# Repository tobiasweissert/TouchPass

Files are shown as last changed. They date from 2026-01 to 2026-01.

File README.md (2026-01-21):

# TouchPass



A hardware password manager that types your passwords when you touch it with an enrolled finger.

TouchPass Demo

## Features

- **6-capture enrollment** - Touch ID style enrollment for better accuracy
- **Dual Keyboard Support** - USB HID or BLE Keyboard (switchable via web UI)
- **WiFi AP Configuration** - Configure via web interface at 192.168.4.1
- **USB Serial Configuration** - Alternative USB-based config (no WiFi interference)
- **10 finger support** - Map passwords to specific fingers on left/right hands
- **Re-enrollment protection** - Re-enrolling a finger overwrites the previous entry
- **ESP32-S3 & ESP32-C6 support** - Works with both chips

## Hardware

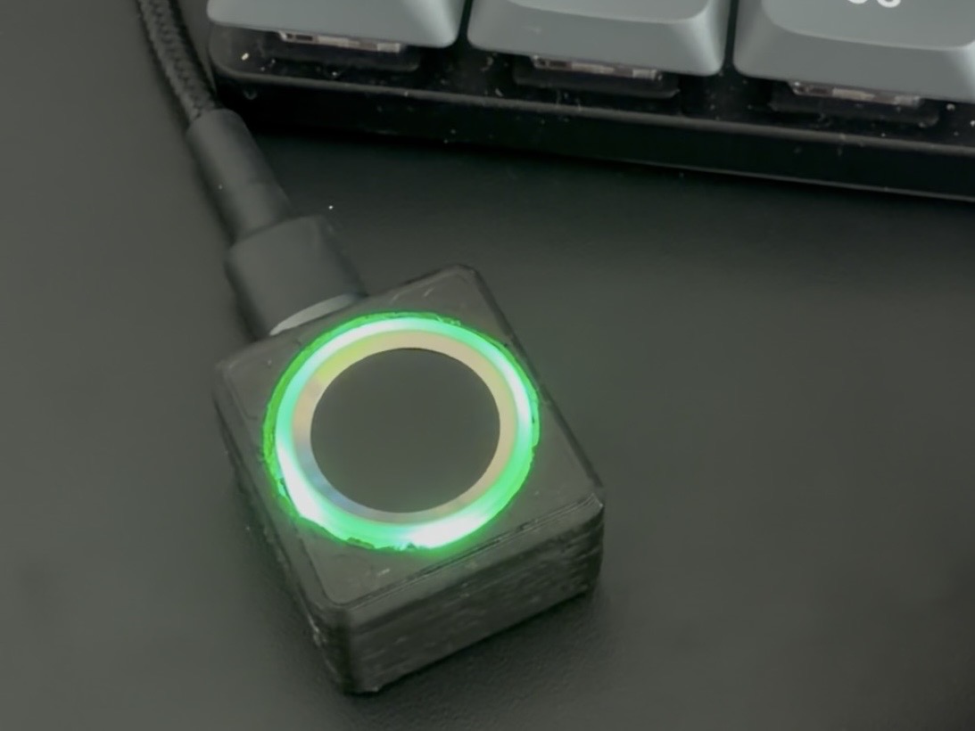
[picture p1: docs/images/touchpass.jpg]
TouchPass Device


| Component | Description |
|---|---|
| Seeed XIAO ESP32-S3 | Recommended - USB HID + WiFi + BLE |
| Seeed XIAO ESP32-C6 | Alternative - BLE only, WiFi 6 |
| R502-A | Capacitive fingerprint sensor with RGB LED |

See [hardware/README.md](hardware/README.md) for wiring diagram and details.

### Wiring

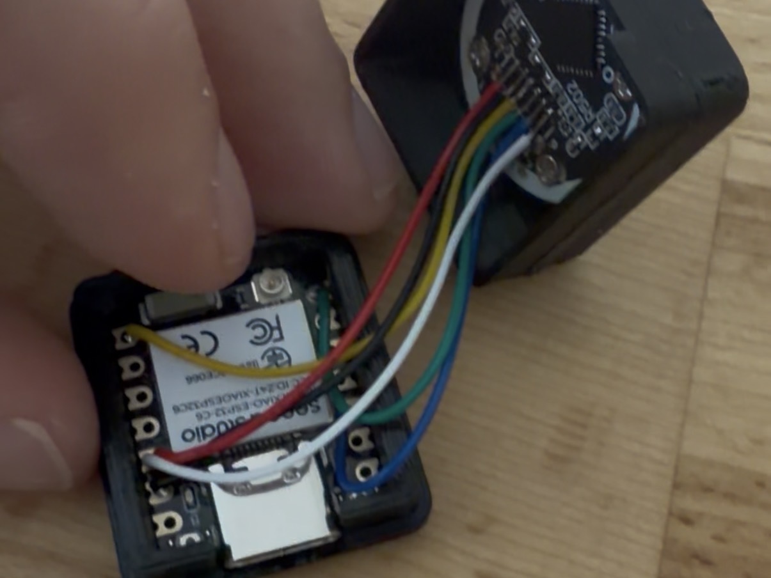
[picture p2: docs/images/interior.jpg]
Interior View
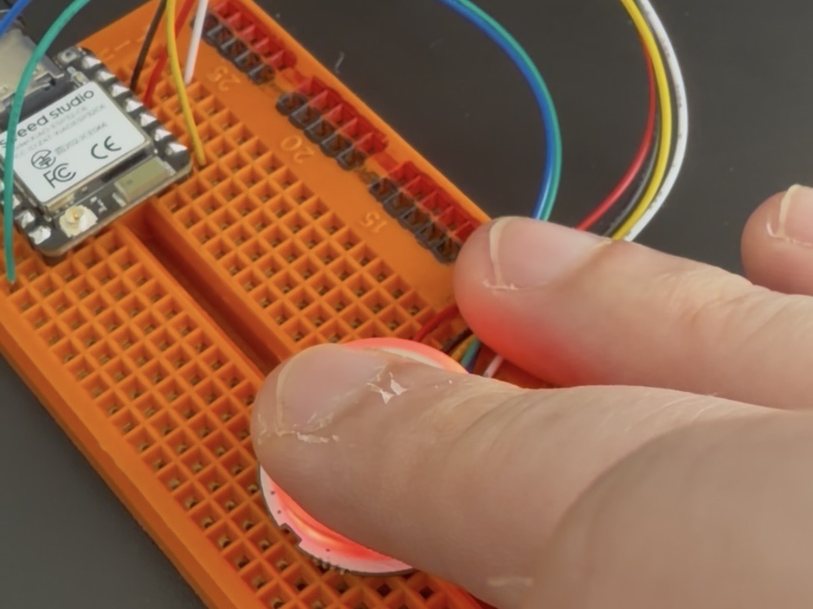
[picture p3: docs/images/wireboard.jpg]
Wiring Board
|  |  |
|:--:|:--:|
| *Interior assembly* | *Wiring detail* |

#### ESP32-S3 Fingerprint Sensor
| R502-A Pin | ESP32-S3 Pin | GPIO | Description |
|---|---|---|---|
| VCC (Red)  | 3V3 | - | Power |
| GND (Black)| GND | - | Ground |
| TXD (Yellow)| D5 | 6 | Sensor TX → ESP32 RX |
| RXD (Green)| D4 | 5 | Sensor RX ← ESP32 TX |
| VT (White) | 3V3 | - | Touch power (always on) |

#### ESP32-C6 Fingerprint Sensor
| R502-A Pin | ESP32-C6 Pin | GPIO | Description |
|---|---|---|---|
| VCC (Red)  | 3V3 | - | Power |
| GND (Black)| GND | - | Ground |
| TXD (Yellow)| D7 | 17 | Sensor TX → ESP32 RX |
| RXD (Green)| D6 | 16 | Sensor RX ← ESP32 TX |
| VT (White) | 3V3 | - | Touch power (always on) |

#### USB Serial Configuration (Alternative to WiFi)
For serial-based configuration without WiFi interference:
- **ESP32-S3**: Uses native USB CDC Serial @ 115200 baud (requires correct USB Mode settings)
- **ESP32-C6**: Uses native USB CDC Serial @ 115200 baud
- No additional wiring required - just USB-C cable
- Web Serial API interface in browser (Chrome/Edge)
- See [docs/serial-configuration.md](docs/serial-configuration.md) for details

## Quick Start

1. **Build** - See [docs/assembly.md](docs/assembly.md)
2. **Flash** - Upload firmware with correct settings:
   ```bash
   arduino-cli compile --fqbn esp32:esp32:XIAO_ESP32S3:USBMode=default,CDCOnBoot=default firmware/firmware.ino
   arduino-cli upload -p /dev/cu.usbmodem1101 --fqbn esp32:esp32:XIAO_ESP32S3:USBMode=default,CDCOnBoot=default firmware/firmware.ino
   ```
   **See [Programming Guide](docs/programming-guide.md) for details**
3. **Configure** - Open `firmware/config.html` in Chrome/Edge → Click "Connect Device"
4. **Enroll** - Tap a finger on the hand diagram, set name and password
5. **Use** - Touch enrolled finger to type password

## Project Structure

```
TouchPass/
├── firmware/          # ESP32 source code
│   ├── firmware.ino   # Main firmware
│   ├── modules/       # Modular components
│   ├── webpage.h      # Embedded web UI
│   ├── config.html    # USB Serial configuration interface
│   └── sketch.json    # Arduino config
├── hardware/          # Wiring, schematics, PCB (future)
├── enclosure/         # 3D printable case
├── docs/              # Documentation
│   ├── assembly.md    # Build instructions
│   ├── programming-guide.md  # Flashing & setup
│   ├── serial-configuration.md  # USB config guide
│   └── images/        # Photos & screenshots
├── LICENSE            # MIT License
└── README.md          # This file
```

## Building

### Requirements

- Arduino IDE or arduino-cli
- ESP32 board support package (v3.x)
- [ESP32-BLE-Keyboard](https://github.com/T-vK/ESP32-BLE-Keyboard) library

### Library Modifications Required

The ESP32-BLE-Keyboard library needs modification to coexist with USBHIDKeyboard. Edit `BleKeyboard.h`:

1. Wrap KEY_* constants with `#ifndef KEY_LEFT_CTRL` guard
2. Wrap KeyReport typedef with `#ifndef _KEYREPORT_DEFINED` guard

Also edit `USBHIDKeyboard.h` in the ESP32 core library:
- Wrap KeyReport typedef with `#ifndef _KEYREPORT_DEFINED` guard

See [docs/library-patches.md](docs/library-patches.md) for details.

### Compile & Upload

**ESP32-S3 (XIAO):**
```bash
cd firmware
arduino-cli compile --fqbn esp32:esp32:XIAO_ESP32S3:USBMode=default,CDCOnBoot=default firmware.ino
arduino-cli upload -p /dev/cu.usbmodem1101 --fqbn esp32:esp32:XIAO_ESP32S3:USBMode=default,CDCOnBoot=default firmware.ino
```

**CRITICAL**: Must use `USBMode=default` (TinyUSB) and `CDCOnBoot=default` (Enabled) for Web Serial API compatibility.
See [Programming Guide](docs/programming-guide.md) for detailed explanation.

**ESP32-C6:**
```bash
cd firmware
arduino-cli compile --fqbn esp32:esp32:XIAO_ESP32C6:PartitionScheme=huge_app .
arduino-cli upload -p /dev/cu.usbmodem* --fqbn esp32:esp32:XIAO_ESP32C6:PartitionScheme=huge_app .
```

**Note**: If the USB port disappears, hold BOOT button while plugging in USB.

## Usage

### Normal Operation

1. Power on the device (blue breathing LED = WiFi on, LED off = WiFi off)
2. Touch enrolled finger on sensor
3. Password is typed automatically via USB or Bluetooth keyboard

### Configuration Mode

**Option 1: WiFi (Web Interface)**
1. Connect to WiFi network "TouchPass" (password: `touchpass`)
2. Open http://192.168.4.1 in any browser
3. Tap a finger on the hand diagram to enroll or edit
4. Set name, password, and optional "press Enter" setting

**Option 2: USB Serial Configuration (Recommended)**
1. Connect via USB-C cable to your computer
2. Open `firmware/config.html` in Chrome or Edge
3. Click "Connect Device" and select TouchPass
4. Visual interface for enrollment and configuration
5. No WiFi interference with fingerprint sensor
6. Uses Web Serial API (see [docs/serial-configuration.md](docs/serial-configuration.md))

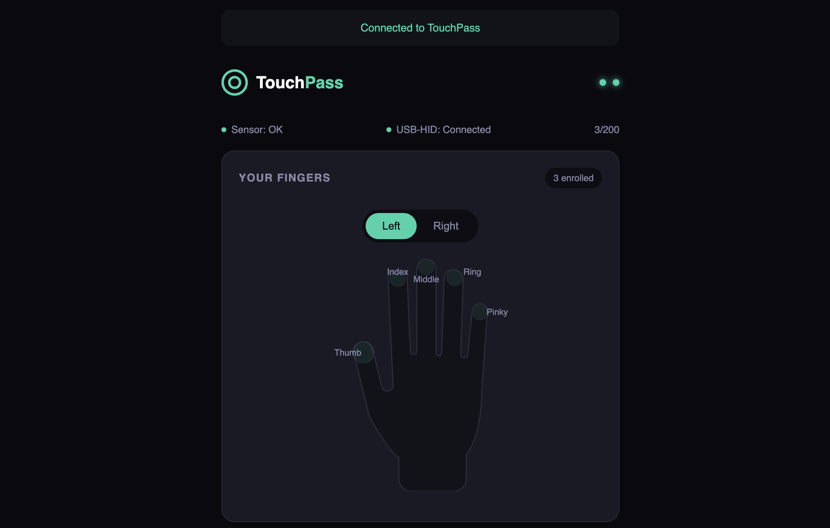
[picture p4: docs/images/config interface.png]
Configuration Interface
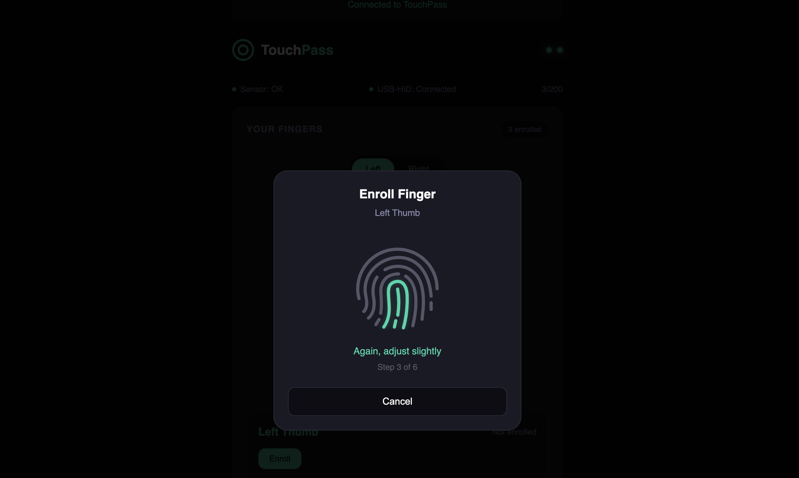
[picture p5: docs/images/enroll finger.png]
Enroll Finger
|  |  |
|:--:|:--:|
| *Main configuration interface* | *Finger enrollment dialog* |

### Toggle WiFi

Hold any finger on sensor for 5 seconds to toggle WiFi on/off.

### Switch Keyboard Mode (USB/BLE)

1. Open web interface at http://192.168.4.1
2. Click on the keyboard status in the top bar (shows "USB" or "BLE")
3. Confirm the switch - device will restart

### LED Indicators

| Pattern | Color | Meaning |
|---|---|---|
| Breathing | Blue | WiFi enabled, standby |
| Off | - | WiFi disabled, standby |
| Breathing | Blue | Enrolling - waiting for finger |
| Flash | Green | Capture success |
| Solid | Green | Finger recognized |
| Solid | Red | Unknown finger / error |

## Platform Differences

| Feature | ESP32-S3 | ESP32-C6 |
|---|---|---|
| USB HID Keyboard | ✓ | ✗ |
| BLE Keyboard | ✓ | ✓ |
| WiFi | ✓ (needs antenna) | ✓ (built-in) |
| Default Mode | USB | BLE |

**ESP32-S3 WiFi Note**: The XIAO ESP32-S3 requires an external antenna connected to the U.FL connector for reliable WiFi.

## Contributing

Contributions welcome!

- Report bugs or suggest features via Issues
- Submit PRs for code improvements
- Design a 3D printable case
- Improve documentation

## Security Notes

- Passwords stored in plain text in flash memory
- WiFi configuration requires physical proximity
- Standard USB HID / BLE HID (no encryption)
- Physical device access = password access
- Consider disabling WiFi after configuration (hold finger 5s)

## License

[MIT](LICENSE)

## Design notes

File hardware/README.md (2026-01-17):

# Hardware

## Components

| Component | Description | Quantity |
|---|---|---|
| Seeed XIAO ESP32-S3 | Recommended - USB HID + BLE | 1 |
| Seeed XIAO ESP32-C6 | Alternative - BLE only | 1 |
| R502-A | Capacitive fingerprint sensor module | 1 |
| External WiFi Antenna | Required for ESP32-S3 | 1 |

## Wiring Diagram

```
R502-A Fingerprint Sensor          XIAO ESP32-S3
┌──────────────────────┐          ┌──────────────┐
│                      │          │              │
│  Pin 1 (VCC)  Red   ─┼──────────┼─── 3V3       │
│  Pin 2 (GND)  Black ─┼──────────┼─── GND       │
│  Pin 3 (TXD)  Yellow┼──────────┼─── D5 (RX)   │
│  Pin 4 (RXD)  Green ─┼──────────┼─── D4 (TX)   │
│  Pin 5 (IRQ)  Blue  ─┼──────────┼─── (unused)  │
│  Pin 6 (VT)   White ─┼──────────┼─── 3V3       │
│                      │          │              │
└──────────────────────┘          └──────────────┘

Configuration Interface: USB cable (UART0 on GPIO43/44 @ 115200 baud)
Note: Arduino IDE must have "USB CDC On Boot: Disabled" to avoid USB HID conflicts
```

## Pin Mapping

The silkscreen labels map to different GPIOs on each chip:

**Note for ESP32-S3:** Using D4/D5 (GPIO5/6) for fingerprint sensor. USB CDC requires "USB CDC On Boot: Disabled" in Arduino IDE.

### ESP32-S3

| Pin/Function | Description | ESP32-S3 Pin | GPIO |
|---|---|---|---|
| **Fingerprint Sensor (UART1)** | | | |
| VCC (Red) | Power 3.3V | 3V3 | - |
| GND (Black) | Ground | GND | - |
| TXD (Yellow) | Sensor TX → ESP RX | D5 | GPIO6 |
| RXD (Green) | Sensor RX ← ESP TX | D4 | GPIO5 |
| IRQ (Blue) | Finger detect | - | (unused) |
| VT (White) | Touch power | 3V3 | - |
| **Configuration Interface** | | | |
| USB Serial | UART0 (USB CDC disabled) | USB-C Port | GPIO43/44 |
| USB HID Keyboard | Native USB | USB-C Port | GPIO19/20 |

### ESP32-C6

| Pin/Function | Description | ESP32-C6 Pin | GPIO |
|---|---|---|---|
| **Fingerprint Sensor (UART1)** | | | |
| VCC (Red) | Power 3.3V | 3V3 | - |
| GND (Black) | Ground | GND | - |
| TXD (Yellow) | Sensor TX → ESP RX | D7 | GPIO17 |
| RXD (Green) | Sensor RX ← ESP TX | D6 | GPIO16 |
| IRQ (Blue) | Finger detect | - | (unused) |
| VT (White) | Touch power | 3V3 | - |
| **Configuration Interface** | | | |
| USB Serial | Native USB CDC | USB-C Port | GPIO19/20 |

## R502-A Wire Colors

| Wire Color | Pin | Function |
|---|-----|---|
| Red | 1 | VCC (3.3V) |
| Black | 2 | GND |
| Yellow | 3 | TXD (sensor output) |
| Green | 4 | RXD (sensor input) |
| Blue | 5 | IRQ (touch interrupt) |
| White | 6 | VT (touch power) |

## Platform Comparison

| Feature | ESP32-S3 | ESP32-C6 |
|---|---|---|
| USB HID Keyboard | ✓ Native | ✗ |
| BLE Keyboard | ✓ | ✓ |
| WiFi | ✓ External antenna | ✓ Built-in |
| Price | ~$7 | ~$5 |
| Recommended | Yes | Budget option |

## ESP32-S3 Notes

### External Antenna Required

The XIAO ESP32-S3 has weak built-in WiFi. You **must** connect the external antenna to the U.FL connector on the bottom-left of the board for WiFi to work.

### USB Port Recovery

If the firmware crashes and USB port disappears:
1. Unplug USB
2. Hold BOOT button
3. Plug in USB while holding BOOT
4. Release BOOT
5. Flash new firmware

## R502-A Sensor Notes

- Operating voltage: 3.3V DC
- Operating current: ~30mA active, ~2μA touch detect
- Serial baud rate: 57600
- Storage capacity: 200 fingerprints
- Built-in RGB LED ring for status feedback
- Capacitive sensing (works through thin materials)

## Future

This folder will contain:
- KiCad schematics
- PCB designs
- Gerber files for manufacturing

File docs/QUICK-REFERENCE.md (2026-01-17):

# TouchPass Quick Reference Card

## Programming Command (Copy-Paste Ready)

### ESP32-S3 (XIAO)
```bash
arduino-cli compile --fqbn esp32:esp32:XIAO_ESP32S3:USBMode=default,CDCOnBoot=default firmware.ino && arduino-cli upload -p /dev/cu.usbmodem1101 --fqbn esp32:esp32:XIAO_ESP32S3:USBMode=default,CDCOnBoot=default firmware.ino
```

### Critical Settings
- **USBMode=default** → USB-OTG (TinyUSB) - Required for Web Serial API
- **CDCOnBoot=default** → CDC Enabled - Required to stay connected after boot

## Common Issues & Fixes

| Problem | Solution |
|---|---|
| **"Port is busy"** | Close browser tab with config.html, wait 3 seconds, retry |
| **Device disappears after upload** | Wrong USB mode! Use `USBMode=default` not `USBMode=hwcdc` |
| **Command timeout in browser** | Wrong USB mode! Switch to TinyUSB (`USBMode=default`) |
| **Can't find device in browser** | Must use Chrome/Edge (not Firefox/Safari), use https:// or localhost |
| **"reader.read() blocking forever"** | Wrong USB mode - using Hardware CDC instead of TinyUSB |

## Upload Checklist

- [ ] Close all browser tabs with config.html
- [ ] Device showing at `/dev/cu.usbmodem1101`
- [ ] Using `USBMode=default` (TinyUSB)
- [ ] Using `CDCOnBoot=default` (Enabled)
- [ ] Upload successful
- [ ] Device reconnects after upload
- [ ] Open config.html in Chrome/Edge
- [ ] Can connect and see data in console

## Verification Commands

```bash
# Check device is connected
arduino-cli board list | grep -i usb

# Monitor serial output
arduino-cli monitor -p /dev/cu.usbmodem1101 -c baudrate=115200

# Verify settings during compile
arduino-cli compile --fqbn esp32:esp32:XIAO_ESP32S3:USBMode=default,CDCOnBoot=default --show-properties firmware.ino | grep -i "usb\|cdc"
```

## USB Mode Comparison

| Mode | Setting | Web Serial | Status |
|---|---|---|---|
| **Hardware CDC** | `USBMode=hwcdc` | ❌ Broken | Don't use |
| **TinyUSB** | `USBMode=default` | ✅ Works | Use this |

## Browser Requirements

- ✅ Chrome 89+
- ✅ Edge 89+
- ✅ Opera
- ❌ Firefox (no Web Serial API)
- ❌ Safari (no Web Serial API)

## File Locations

- Firmware: `firmware/firmware.ino`
- Config UI: `firmware/config.html`
- Documentation: `docs/programming-guide.md`

## Expected Console Output (Success)

```
[Serial] Port opened successfully
[Serial] Text streams configured successfully
[Serial] === READ LOOP STARTING ===
[Serial] Loop iteration #1, waiting for data...
[Serial] 📥 Received data: {"debug":"Serial initialized"}
[Serial] ✓ Parsed JSON: {debug: "Serial initialized"}
[Serial] Sending command #1: get_status
[Serial] ✓ Command #1 write complete
[Serial] 📥 Received data: {"status":"ok","data":{...},"id":1}
[Serial] ✓ Command #1 SUCCESS
```

## Support

- Full guide: `docs/programming-guide.md`
- Issues: https://github.com/anthropics/TouchPass/issues (if public)

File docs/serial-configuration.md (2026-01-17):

# Serial Configuration Guide

TouchPass supports both WiFi and USB Serial configuration. USB Serial allows you to configure the device without WiFi interference with the fingerprint sensor.

## Hardware Setup

### ESP32-S3
Simply connect via USB-C cable to your computer:
- **USB-C Cable** → Computer
- No additional wiring required
- Uses UART0 on GPIO43/44 (accessed through USB-C)
- **Important**: Arduino IDE must have "USB CDC On Boot: Disabled" to avoid USB HID conflicts

### ESP32-C6
Simply connect via USB-C cable to your computer:
- **USB-C Cable** → Computer
- No additional wiring required
- Uses native USB CDC Serial (GPIO19/20 internally)

**Note**: USB Serial runs at **115200 baud**, 8N1.

## Serial Protocol

Commands are sent as JSON over serial, one command per line (terminated with `\n`).

### Command Format
```json
{"cmd": "command_name", "params": {...}, "id": 123}
```

- `cmd` (required): Command name
- `params` (optional): Command parameters as JSON object
- `id` (optional): Request ID for matching responses

### Response Format
```json
{"status": "ok", "data": {...}, "id": 123}
```

Or on error:
```json
{"status": "error", "message": "error description", "id": 123}
```

## Available Commands

### System Info
```bash
{"cmd": "get_system_info"}
```
Returns chip type, firmware version, free heap, and WiFi status.

### Get Status
```bash
{"cmd": "get_status"}
```
Returns sensor status, fingerprint count, and capacity.

### List Fingers
```bash
{"cmd": "get_fingers"}
```
Returns array of enrolled fingerprints with IDs and names.

### Enroll Finger
```bash
{"cmd": "enroll_start", "params": {"name": "Gmail", "password": "mypassword", "pressEnter": true, "finger": 0}}
```
- `name` (required): Display name for the fingerprint
- `password` (optional): Password to type when finger is detected
- `pressEnter` (optional): Press Enter after typing password (default: false)
- `finger` (optional): Finger ID 0-9 for mapping (0=left thumb, 1=left index, etc.)

Then poll enrollment status:
```bash
{"cmd": "enroll_status"}
```

### Get Finger Details
```bash
{"cmd": "get_finger", "params": {"id": 0}}
```
Returns name, password status, and press-enter setting for a specific slot.

### Update Finger
```bash
{"cmd": "update_finger", "params": {"id": 0, "name": "New Name", "password": "newpass", "pressEnter": false}}
```

### Delete Finger
```bash
{"cmd": "delete_finger", "params": {"id": 0}}
```

### Clear All Fingerprints
```bash
{"cmd": "empty_library"}
```

### Get Keyboard Status
```bash
{"cmd": "get_keyboard_mode"}
```
Returns current keyboard mode (USB or BLE).

### Set Keyboard Mode
```bash
{"cmd": "set_keyboard_mode", "params": {"mode": "usb"}}
```
Mode can be `"usb"` or `"ble"`. Device will restart after mode change.

### Reboot
```bash
{"cmd": "reboot"}
```

## Example: Enroll a Finger

```bash
# Start enrollment
{"cmd": "enroll_start", "params": {"name": "GitHub", "password": "ghp_token123", "pressEnter": true, "finger": 1}}

# Response:
# {"status":"ok","data":{"ok":true,"status":"Place finger on sensor"},"id":-1}

# Poll enrollment status (repeat until done)
{"cmd": "enroll_status"}

# Response (in progress):
# {"status":"ok","data":{"state":1,"totalSteps":6,"step":1,"captured":false,"phase":"center","message":"Place finger on sensor","done":false}}

# Response (completed):
# {"status":"ok","data":{"state":9,"totalSteps":6,"step":6,"captured":true,"phase":"edges","message":"","done":true,"ok":true,"name":"GitHub","status":"Enrolled successfully"}}
```

## Python Example

```python
import serial
import json
import time

# Open serial port
# Linux/Windows: '/dev/ttyACM0' or 'COM3'
# macOS: '/dev/cu.usbmodem*' (find with: ls /dev/cu.usbmodem*)
ser = serial.Serial('/dev/cu.usbmodem101', 115200, timeout=1)
time.sleep(2)  # Wait for device ready

def send_command(cmd, params=None, req_id=1):
    command = {"cmd": cmd, "id": req_id}
    if params:
        command["params"] = params
    ser.write((json.dumps(command) + '\n').encode())
    response = ser.readline().decode().strip()
    return json.loads(response)

# Get system info
info = send_command("get_system_info")
print(f"Chip: {info['data']['chip']}")
print(f"Firmware: {info['data']['firmware']}")

# List enrolled fingers
fingers = send_command("get_fingers")
print(f"Enrolled: {len(fingers['data']['fingers'])} fingers")

# Enroll new finger
result = send_command("enroll_start", {
    "name": "MyPassword",
    "password": "secret123",
    "pressEnter": True,
    "finger": 0
})
print(result['data']['status'])

# Poll enrollment
while True:
    status = send_command("enroll_status")
    data = status['data']
    print(f"Step {data['step']}/6: {data['message']}")
    if data['done']:
        print(f"Result: {data['status']}")
        break
    time.sleep(0.5)

ser.close()
```

## Web Serial API (Browser)

You can also configure TouchPass directly from a browser using the Web Serial API:

```html
<!DOCTYPE html>
<html>
<body>
  <button onclick="connect()">Connect to TouchPass</button>
  <button onclick="getStatus()">Get Status</button>
  <pre id="output"></pre>

  <script>
    let port;
    let reader;
    let writer;

    async function connect() {
      port = await navigator.serial.requestPort();
      await port.open({ baudRate: 115200 });

      const decoder = new TextDecoderStream();
      const readableStreamClosed = port.readable.pipeTo(decoder.writable);
      reader = decoder.readable.getReader();

      const encoder = new TextEncoderStream();
      const writableStreamClosed = encoder.readable.pipeTo(port.writable);
      writer = encoder.writable.getWriter();

      document.getElementById('output').textContent = 'Connected!';

      // Read responses
      readLoop();
    }

    async function readLoop() {
      while (true) {
        const { value, done } = await reader.read();
        if (done) break;
        document.getElementById('output').textContent = value;
      }
    }

    async function sendCommand(cmd, params) {
      const command = { cmd, params, id: Date.now() };
      await writer.write(JSON.stringify(command) + '\n');
    }

    async function getStatus() {
      await sendCommand('get_status');
    }
  </script>
</body>
</html>
```

## Advantages of USB Serial Configuration

1. **No WiFi interference** - ESP32-S3 uses UART0 (GPIO43/44) for config, fingerprint sensor on UART1 (GPIO40/41)
2. **No additional wiring** - Just plug in the USB-C cable you use for programming
3. **Works without WiFi** - Configure even with WiFi disabled
4. **Automation-friendly** - Easy to script with Python, Node.js, etc.
5. **Web Serial API** - Configure from browser without installing drivers
6. **Debugging** - View real-time responses and system info

## WiFi Configuration Still Available

The web interface at http://192.168.4.1 still works as before. Serial configuration is an additional option, not a replacement.

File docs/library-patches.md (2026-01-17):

# Library Patches for USB + BLE Keyboard Coexistence

The ESP32-BLE-Keyboard library and the built-in USBHIDKeyboard library both define the same constants and types, causing compilation errors when both are included. These patches allow both libraries to coexist.

## Problem

Both libraries define:
- `KEY_LEFT_CTRL`, `KEY_LEFT_SHIFT`, etc. (key constants)
- `KeyReport` typedef (key report structure)

## Solution

Add preprocessor guards to prevent duplicate definitions.

## Patch 1: BleKeyboard.h

**File location**: `~/Documents/Arduino/libraries/ESP32_BLE_Keyboard/src/BleKeyboard.h`

### Change 1: Wrap KEY_* constants

Find this block (around line 15):
```cpp
const uint8_t KEY_LEFT_CTRL = 0x80;
const uint8_t KEY_LEFT_SHIFT = 0x81;
// ... more KEY_* definitions ...
const uint8_t KEY_F24 = 0xFB;
```

Wrap it with:
```cpp
#ifndef KEY_LEFT_CTRL
const uint8_t KEY_LEFT_CTRL = 0x80;
const uint8_t KEY_LEFT_SHIFT = 0x81;
// ... keep all KEY_* definitions ...
const uint8_t KEY_F24 = 0xFB;
#endif
```

### Change 2: Wrap KeyReport typedef

Find this block (around line 85):
```cpp
//  Low level key report: up to 6 keys and shift, ctrl etc at once
typedef struct
{
  uint8_t modifiers;
  uint8_t reserved;
  uint8_t keys[6];
} KeyReport;
```

Change to:
```cpp
// Only define KeyReport if not already defined by USBHIDKeyboard
#ifndef _KEYREPORT_DEFINED
#define _KEYREPORT_DEFINED
//  Low level key report: up to 6 keys and shift, ctrl etc at once
typedef struct
{
  uint8_t modifiers;
  uint8_t reserved;
  uint8_t keys[6];
} KeyReport;
#endif
```

## Patch 2: USBHIDKeyboard.h

**File location**: `~/Library/Arduino15/packages/esp32/hardware/esp32/3.x.x/libraries/USB/src/USBHIDKeyboard.h`

Find this block (around line 144):
```cpp
//  Low level key report: up to 6 keys and shift, ctrl etc at once
typedef struct {
  uint8_t modifiers;
  uint8_t reserved;
  uint8_t keys[6];
} KeyReport;
```

Change to:
```cpp
//  Low level key report: up to 6 keys and shift, ctrl etc at once
#ifndef _KEYREPORT_DEFINED
#define _KEYREPORT_DEFINED
typedef struct {
  uint8_t modifiers;
  uint8_t reserved;
  uint8_t keys[6];
} KeyReport;
#endif
```

## Include Order

In your sketch, include USBHIDKeyboard first, then BleKeyboard:

```cpp
#include <USB.h>
#include <USBHIDKeyboard.h>
#include <BleKeyboard.h>
```

This ensures USBHIDKeyboard's KEY_* macros are defined first, and BleKeyboard will skip its duplicate definitions.

## Related Issue

See [ESP32-BLE-Keyboard PR #253](https://github.com/T-vK/ESP32-BLE-Keyboard/pull/253) for the upstream fix.

## Verification

After applying patches, this should compile without errors:

```cpp
#include <USB.h>
#include <USBHIDKeyboard.h>
#include <BleKeyboard.h>

USBHIDKeyboard usbKeyboard;
BleKeyboard bleKeyboard("Test", "Test", 100);

void setup() {
    // Both can be instantiated
}

void loop() {}
```

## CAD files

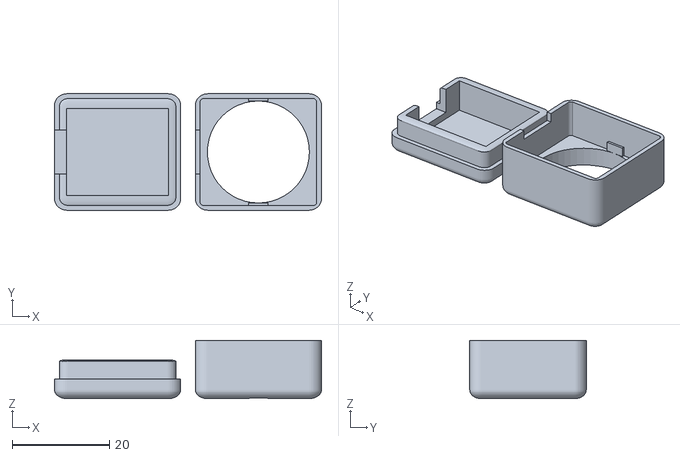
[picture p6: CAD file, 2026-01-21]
enclosure/case touchPass.stl
55.0 x 24.0 x 12.0

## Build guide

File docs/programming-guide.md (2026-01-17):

# TouchPass Programming Guide

## Correct Firmware Upload Procedure

### Arduino CLI Command

Use this command to compile and upload firmware to the ESP32-S3:

```bash
arduino-cli compile --fqbn esp32:esp32:XIAO_ESP32S3:USBMode=default,CDCOnBoot=default firmware.ino
arduino-cli upload -p /dev/cu.usbmodem1101 --fqbn esp32:esp32:XIAO_ESP32S3:USBMode=default,CDCOnBoot=default firmware.ino
```

### Critical Settings Explained

#### 1. **USBMode=default** (USB-OTG TinyUSB)
- **Required for Web Serial API compatibility**
- Uses software-based USB CDC implementation via TinyUSB
- Provides proper bidirectional communication
- **DO NOT use `USBMode=hwcdc`** (Hardware CDC and JTAG mode has issues with Web Serial API)

#### 2. **CDCOnBoot=default** (Enabled)
- Ensures USB Serial port remains available after firmware boots
- Without this, the device only appears in bootloader mode
- Required for the browser to maintain connection after reset

## Why This Matters

### USB Mode Comparison

| Mode | Value | Description | Web Serial API |
|---|---|---|---|
| **Hardware CDC and JTAG** | `USBMode=hwcdc` | Uses built-in USB Serial/JTAG controller (hardware-based) | ❌ Has bidirectional communication issues |
| **USB-OTG (TinyUSB)** | `USBMode=default` | Software-based CDC via TinyUSB stack | ✅ Full compatibility |

### What You'll See

**Correct Setup (USB-OTG):**
- Device shows as "Serial Port (USB)" in Arduino CLI
- Browser can send commands and receive responses
- Bidirectional communication works perfectly

**Incorrect Setup (Hardware CDC):**
- Device shows as "USB JTAG/serial debug unit"
- Browser can send but cannot receive data
- `reader.read()` blocks forever
- Commands timeout after 5 seconds

## Step-by-Step Upload Process

### 1. Close Browser Connection
```bash
# The serial port must not be in use
# Close any browser tabs with config.html open
```

### 2. Check Device Connection
```bash
arduino-cli board list | grep -i usb
# Should show: /dev/cu.usbmodem1101  serial   Serial Port (USB)
```

### 3. Compile Firmware
```bash
cd firmware
arduino-cli compile --fqbn esp32:esp32:XIAO_ESP32S3:USBMode=default,CDCOnBoot=default firmware.ino
```

### 4. Upload Firmware
```bash
arduino-cli upload -p /dev/cu.usbmodem1101 --fqbn esp32:esp32:XIAO_ESP32S3:USBMode=default,CDCOnBoot=default firmware.ino
```

### 5. Verify Device Reconnects
```bash
sleep 3
arduino-cli board list | grep -i usb
# Device should still be present at /dev/cu.usbmodem1101
```

### 6. Test with Browser
1. Open `config.html` in Chrome or Edge
2. Open browser console (Cmd+Option+I or F12)
3. Click "Connect Device"
4. Select "ESP32 Family Device" or similar
5. Should see debug messages and successful connection

## Quick Reference

### One-Line Compile + Upload
```bash
arduino-cli compile --fqbn esp32:esp32:XIAO_ESP32S3:USBMode=default,CDCOnBoot=default firmware.ino && arduino-cli upload -p /dev/cu.usbmodem1101 --fqbn esp32:esp32:XIAO_ESP32S3:USBMode=default,CDCOnBoot=default firmware.ino
```

### Makefile (Optional)
Create a `Makefile` in the firmware directory:

```makefile
FQBN = esp32:esp32:XIAO_ESP32S3:USBMode=default,CDCOnBoot=default
PORT = /dev/cu.usbmodem1101

compile:
	arduino-cli compile --fqbn $(FQBN) firmware.ino

upload:
	arduino-cli upload -p $(PORT) --fqbn $(FQBN) firmware.ino

all: compile upload

.PHONY: compile upload all
```

Then use:
```bash
make all
```

## Troubleshooting

### "Port is busy" Error
**Problem:** `Could not open /dev/cu.usbmodem1101, the port is busy`

**Solution:**
1. Close all browser tabs with config.html
2. Close Arduino Serial Monitor if open
3. Wait 2-3 seconds
4. Try upload again

### Device Disappears After Boot
**Problem:** Device only visible during bootloader mode

**Solution:** You're using wrong USB mode or CDC setting:
```bash
# Check current settings
arduino-cli compile --fqbn esp32:esp32:XIAO_ESP32S3:USBMode=default,CDCOnBoot=default --show-properties firmware.ino | grep -i "usb\|cdc"

# Should show:
# ARDUINO_USB_MODE=1
# ARDUINO_USB_CDC_ON_BOOT=1
```

### Command Timeouts in Browser
**Problem:** Browser sends commands but gets "Command timeout" after 5 seconds

**Symptoms:**
- `reader.read()` blocks forever
- No "📥 Received data" messages in console
- No loop iteration logs beyond #1

**Solution:** Wrong USB mode! Use `USBMode=default` (TinyUSB), NOT `USBMode=hwcdc`

### Monitor Serial Output (Debug)
To see what the ESP32 is outputting:
```bash
arduino-cli monitor -p /dev/cu.usbmodem1101 -c baudrate=115200
```

Press Ctrl+C to exit.

## Board Configuration Reference

Available options for XIAO_ESP32S3:

| Option | Recommended | Alternative |
|---|---|---|
| **USB Mode** | `USBMode=default` (TinyUSB) | `USBMode=hwcdc` (Hardware CDC - don't use) |
| **USB CDC On Boot** | `CDCOnBoot=default` (Enabled) | `CDCOnBoot=cdc` (Disabled) |
| **Upload Speed** | `UploadSpeed=921600` (default) | 115200, 230400, 460800 |
| **CPU Frequency** | `CPUFreq=240` (default) | 160, 80, 40, 20, 10 |

## Web Serial API Requirements

- **Browser:** Chrome 89+, Edge 89+, or Opera (not Firefox or Safari)
- **Connection:** Must be HTTPS or localhost (file:// works)
- **USB Mode:** TinyUSB (`USBMode=default`)
- **CDC On Boot:** Enabled (`CDCOnBoot=default`)

## References

- [ESP32-S3 USB Serial/JTAG Controller](https://docs.espressif.com/projects/esp-idf/en/v5.0/esp32s3/api-guides/usb-serial-jtag-console.html)
- [ESP32-S3 USB OTG Console](https://docs.espressif.com/projects/esp-idf/en/stable/esp32s3/api-guides/usb-otg-console.html)
- [USB Settings for ESP32-S3 in PlatformIO](https://thingpulse.com/usb-settings-for-logging-with-the-esp32-s3-in-platformio/)
- [Web Serial API Documentation](https://developer.mozilla.org/en-US/docs/Web/API/Serial)

## Summary

**Always use these exact settings for TouchPass:**
```
--fqbn esp32:esp32:XIAO_ESP32S3:USBMode=default,CDCOnBoot=default
```

This ensures:
- ✅ USB-OTG (TinyUSB) mode for Web Serial API compatibility
- ✅ USB CDC stays available after boot
- ✅ Bidirectional serial communication works
- ✅ Browser can send commands AND receive responses

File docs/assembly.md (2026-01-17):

# Assembly Guide

Step-by-step instructions to build your TouchPass device.

## Prerequisites

### Tools Needed
- Soldering iron (optional, for permanent connections)
- Wire strippers
- Jumper wires (female-to-female recommended)

### Components
- 1x Seeed XIAO ESP32-C6
- 1x R502-A Fingerprint Sensor
- 6x Jumper wires

## Step 1: Wiring

### Standard Wiring (ESP32-C6 / Always-On)

Connect the R502-A sensor to the ESP32-C6:

| R502-A Wire | Color (typical) | ESP32-C6 Pin |
|---|---|---|
| Pin 1 (VCC) | Red | 3V3 |
| Pin 2 (GND) | Black | GND |
| Pin 3 (TXD) | Yellow | D7 |
| Pin 4 (RXD) | Green | D6 |
| Pin 5 (IRQ) | Blue | D2 (optional) |
| Pin 6 (VT)  | White | 3V3 |

### Low-Power Wiring (ESP32-S3 / Wake-on-Touch)

For battery-powered applications, use this wiring to reduce idle power from 30mA to 2µA:

| R502-A Wire | Color (typical) | ESP32-S3 Pin | Notes |
|---|---|---|---|
| Pin 1 (VCC) | Red | GPIO4 | Switched power (40mA drive) |
| Pin 2 (GND) | Black | GND | |
| Pin 3 (TXD) | Yellow | D7 (GPIO17) | ESP32 RX |
| Pin 4 (RXD) | Green | D6 (GPIO16) | ESP32 TX |
| Pin 5 (IRQ) | Blue | GPIO2 | Touch wake interrupt |
| Pin 6 (VT)  | White | 3V3 | Always on for touch sensing |

**How it works:**
- VT stays powered (3V3) to enable capacitive touch detection (2µA)
- When a finger touches the sensor, IRQ triggers an interrupt
- ESP32 powers on VCC via GPIO4 (configured for 40mA output)
- After 5 seconds of inactivity, VCC is powered off to save power

> **Note**: Wire colors may vary by manufacturer. Always verify with your sensor's datasheet.

## Step 2: Flash Firmware

1. Install Arduino IDE or arduino-cli
2. Install ESP32 board support
3. Install the BleKeyboard library
4. Open `firmware/firmware.ino`
5. Select board: **XIAO ESP32-C6**
6. Select partition scheme: **Huge APP**
7. Upload

```bash
# Or using arduino-cli:
cd firmware
arduino-cli compile --fqbn esp32:esp32:XIAO_ESP32C6:PartitionScheme=huge_app .
arduino-cli upload -p /dev/cu.usbmodem* --fqbn esp32:esp32:XIAO_ESP32C6:PartitionScheme=huge_app .
```

## Step 3: First Boot

1. Power on via USB-C
2. The sensor LED should briefly flash green (sensor OK)
3. The device is now in standby mode

## Step 4: Configuration

1. Hold any finger on sensor for 5 seconds
2. LED starts blue breathing = WiFi enabled
3. Connect to `TouchPass` WiFi (password: `touchpass`)
4. Open http://192.168.4.1
5. Enroll your first finger

## Step 5: Pairing

1. On your computer/phone, search for Bluetooth devices
2. Pair with `TouchPass`
3. Test by scanning an enrolled finger - it should type the password

## Troubleshooting

### Sensor not responding
- Check wiring, especially TX/RX (they cross over)
- Verify 3.3V power on both VCC and VT pins
- For ESP32-S3 low-power mode: Check serial monitor for "[POWER]" messages

### WiFi not starting
- Hold finger for full 5 seconds
- Try with an enrolled finger

### Bluetooth not typing
- Ensure device is paired
- Check that a text field is focused
- Re-pair if needed

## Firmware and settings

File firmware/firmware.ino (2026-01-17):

// TouchPass - Hardware Password Manager
// ESP32-S3/C6 + R502-A Fingerprint Sensor + USB/BLE Keyboard
//
// Wiring (ESP32-S3):
//   Fingerprint: VCC->3V3, GND->GND, TXD->D5 (GPIO6), RXD->D4 (GPIO5), VT->3V3
//   Note: D4/D5 are silkscreen labels on Seeed XIAO ESP32-S3 (actual GPIOs: D4=GPIO5, D5=GPIO6)
//
// IMPORTANT: Upload with correct Arduino CLI flags for Web Serial API compatibility:
//   --fqbn esp32:esp32:XIAO_ESP32S3:USBMode=default,CDCOnBoot=default
//   USBMode=default   -> USB-OTG (TinyUSB) mode (required for Web Serial API)
//   CDCOnBoot=default -> USB CDC stays enabled after boot (required for browser connection)
//
// Config: USB-C cable, Serial @ 115200 baud

#include "sdkconfig.h"
#include <HardwareSerial.h>
#include <Preferences.h>
#include <ArduinoJson.h>
#include "SerialCommandHandler.h"

#include <USB.h>
#include <USBHIDKeyboard.h>
#include <BleKeyboard.h>

#if CONFIG_IDF_TARGET_ESP32S3
  #define FP_TX_PIN 5   // D4 - Fingerprint sensor TX (GPIO5)
  #define FP_RX_PIN 6   // D5 - Fingerprint sensor RX (GPIO6)
  // Config serial uses UART0 (GPIO43/44) via Serial object when USB CDC On Boot is disabled
#else
  #define FP_TX_PIN 16
  #define FP_RX_PIN 17
#endif

#define FP_HEADER 0xEF01
#define FP_DEFAULT_ADDR 0xFFFFFFFF
#define FP_CMD_PACKET 0x01

#define CMD_GENIMG 0x01
#define CMD_IMG2TZ 0x02
#define CMD_SEARCH 0x04
#define CMD_REGMODEL 0x05
#define CMD_STORE 0x06
#define CMD_DELETCHAR 0x0C
#define CMD_EMPTY 0x0D
#define CMD_READSYSPARA 0x0F
#define CMD_TEMPLATENUM 0x1D
#define CMD_READINDEXTABLE 0x1F
#define CMD_AURALEDCONFIG 0x35
#define CMD_CHECKSENSOR 0x36
#define CMD_HANDSHAKE 0x40

#define LED_RED 0x01
#define LED_GREEN 0x04
#define LED_FLASHING 0x02
#define LED_ON 0x03
#define LED_OFF 0x04

HardwareSerial fpSerial(1);
SerialCommandHandler cmdHandler;

// Both keyboard types available
USBHIDKeyboard usbKeyboard;
BleKeyboard bleKeyboard("TouchPass", "Anthropic", 100);
bool usbInitialized = false;
bool bleInitialized = false;
bool useUsb = false;  // Default to BLE for ESP32-S3 (USB Serial for config only)

Preferences prefs;

uint32_t fpAddress = FP_DEFAULT_ADDR;
uint16_t templateCount = 0;
uint16_t librarySize = 200;
String lastStatus = "Ready";
bool sensorOk = false;

enum EnrollState {
    ENROLL_IDLE,
    ENROLL_CAPTURE_1, ENROLL_LIFT_1,
    ENROLL_CAPTURE_2, ENROLL_LIFT_2,
    ENROLL_CAPTURE_3, ENROLL_LIFT_3,
    ENROLL_CAPTURE_4, ENROLL_LIFT_4,
    ENROLL_CAPTURE_5, ENROLL_LIFT_5,
    ENROLL_CAPTURE_6,
    ENROLL_MERGING,
    ENROLL_DONE
};

EnrollState enrollState = ENROLL_IDLE;
String pendingFingerName = "";
String pendingFingerPassword = "";
bool pendingPressEnter = false;
int16_t pendingSlot = -1;
int pendingFingerId = -1;
bool enrollSuccess = false;
String enrollError = "";
unsigned long enrollTimeout = 0;

const char* enrollMessages[] = {
    "Place finger on sensor",
    "Lift and place again",
    "Again, adjust slightly",
    "Now adjust your grip",
    "Place again",
    "One more time"
};

String lastDetectedFinger = "";
int lastDetectedId = -1;
int lastDetectedScore = 0;
uint8_t lastDetectResult = 0xFF;
bool newDetectionAvailable = false;

uint8_t rxBuffer[256];

bool isKeyboardConnected() {
    if (useUsb) {
        return usbInitialized;
    } else {
        return bleKeyboard.isConnected();
    }
}

String getKeyboardMode() {
    return useUsb ? "USB-HID" : "BLE";
}

void typePassword(uint16_t fingerId) {
    String pwd = getFingerPassword(fingerId);
    if (pwd.length() == 0 || !isKeyboardConnected()) return;

    if (useUsb) {
        usbKeyboard.releaseAll();
        delay(50);
        for (unsigned int i = 0; i < pwd.length(); i++) {
            usbKeyboard.print(String(pwd[i]));
            delay(10);
        }
        if (getFingerPressEnter(fingerId)) {
            delay(50);
            usbKeyboard.write(KEY_RETURN);
        }
        usbKeyboard.releaseAll();
    } else {
        bleKeyboard.releaseAll();
        delay(50);
        for (unsigned int i = 0; i < pwd.length(); i++) {
            bleKeyboard.print(String(pwd[i]));
            delay(30);
        }
        if (getFingerPressEnter(fingerId)) {
            delay(50);
            bleKeyboard.write(KEY_RETURN);
        }
        bleKeyboard.releaseAll();
    }
}

uint16_t sendCommand(uint8_t cmd, uint8_t* data, uint16_t dataLen) {
    uint16_t len = dataLen + 3;
    uint16_t sum = FP_CMD_PACKET + (len >> 8) + (len & 0xFF) + cmd;

    fpSerial.write((FP_HEADER >> 8) & 0xFF);
    fpSerial.write(FP_HEADER & 0xFF);
    fpSerial.write((fpAddress >> 24) & 0xFF);
    fpSerial.write((fpAddress >> 16) & 0xFF);
    fpSerial.write((fpAddress >> 8) & 0xFF);
    fpSerial.write(fpAddress & 0xFF);
    fpSerial.write(FP_CMD_PACKET);
    fpSerial.write((len >> 8) & 0xFF);
    fpSerial.write(len & 0xFF);
    fpSerial.write(cmd);

    for (uint16_t i = 0; i < dataLen; i++) {
        fpSerial.write(data[i]);
        sum += data[i];
    }

    fpSerial.write((sum >> 8) & 0xFF);
    fpSerial.write(sum & 0xFF);
    return len + 9;
}

int16_t receiveResponse(uint8_t* buffer, uint16_t timeout) {
    unsigned long start = millis();
    uint16_t idx = 0;
    uint16_t packetLen = 0;
    bool headerFound = false;

    while (millis() - start < timeout) {
        if (fpSerial.available()) {
            uint8_t b = fpSerial.read();
            buffer[idx++] = b;

            if (idx == 2) {
                if (buffer[0] == 0xEF && buffer[1] == 0x01) {
                    headerFound = true;
                } else {
                    buffer[0] = buffer[1];
                    idx = 1;
                }
            }

            if (headerFound && idx == 9) {
                packetLen = (buffer[7] << 8) | buffer[8];
            }

            if (headerFound && idx >= 9 && idx >= 9 + packetLen) {
                return idx;
            }

            if (idx >= sizeof(rxBuffer) - 1) return -1;
        }
    }
    return headerFound ? idx : -1;
}

uint8_t getConfirmCode(uint8_t* buffer, int16_t len) {
    if (len < 10) return 0xFF;
    return buffer[9];
}

bool checkSensorConnection() {
    sendCommand(CMD_HANDSHAKE, NULL, 0);
    int16_t len = receiveResponse(rxBuffer, 500);
    if (len > 0 && getConfirmCode(rxBuffer, len) == 0x00) {
        sensorOk = true;
        return true;
    }
    sendCommand(CMD_CHECKSENSOR, NULL, 0);
    len = receiveResponse(rxBuffer, 500);
    sensorOk = (len > 0 && getConfirmCode(rxBuffer, len) == 0x00);
    return sensorOk;
}

uint16_t getTemplateCount() {
    sendCommand(CMD_TEMPLATENUM, NULL, 0);
    int16_t len = receiveResponse(rxBuffer, 500);
    if (len > 0 && getConfirmCode(rxBuffer, len) == 0x00) {
        templateCount = (rxBuffer[10] << 8) | rxBuffer[11];
    }
    return templateCount;
}

bool readSysParams() {
    sendCommand(CMD_READSYSPARA, NULL, 0);
    int16_t len = receiveResponse(rxBuffer, 500);
    if (len > 0 && getConfirmCode(rxBuffer, len) == 0x00) {
        librarySize = (rxBuffer[14] << 8) | rxBuffer[15];
        return true;
    }
    return false;
}

bool setLED(uint8_t mode, uint8_t speed, uint8_t color, uint8_t count) {
    uint8_t data[4] = {mode, speed, color, count};
    sendCommand(CMD_AURALEDCONFIG, data, 4);
    int16_t len = receiveResponse(rxBuffer, 500);
    return (len > 0 && getConfirmCode(rxBuffer, len) == 0x00);
}

uint8_t captureImage() {
    sendCommand(CMD_GENIMG, NULL, 0);
    int16_t len = receiveResponse(rxBuffer, 3000);
    return (len > 0) ? getConfirmCode(rxBuffer, len) : 0xFF;
}

uint8_t generateChar(uint8_t bufferId) {
    uint8_t data[1] = {bufferId};
    sendCommand(CMD_IMG2TZ, data, 1);
    int16_t len = receiveResponse(rxBuffer, 2000);
    return (len > 0) ? getConfirmCode(rxBuffer, len) : 0xFF;
}

uint8_t createTemplate() {
    sendCommand(CMD_REGMODEL, NULL, 0);
    int16_t len = receiveResponse(rxBuffer, 2000);
    return (len > 0) ? getConfirmCode(rxBuffer, len) : 0xFF;
}

uint8_t storeTemplate(uint8_t bufferId, uint16_t id) {
    uint8_t data[3] = {bufferId, (uint8_t)(id >> 8), (uint8_t)(id & 0xFF)};
    sendCommand(CMD_STORE, data, 3);
    int16_t len = receiveResponse(rxBuffer, 2000);
    return (len > 0) ? getConfirmCode(rxBuffer, len) : 0xFF;
}

uint8_t searchFingerprint(uint8_t bufferId, uint16_t startId, uint16_t count, uint16_t* matchId, uint16_t* score) {
    uint8_t data[5] = {bufferId, (uint8_t)(startId >> 8), (uint8_t)(startId & 0xFF),
                       (uint8_t)(count >> 8), (uint8_t)(count & 0xFF)};
    sendCommand(CMD_SEARCH, data, 5);
    int16_t len = receiveResponse(rxBuffer, 3000);
    if (len > 0) {
        uint8_t code = getConfirmCode(rxBuffer, len);
        if (code == 0x00) {
            *matchId = (rxBuffer[10] << 8) | rxBuffer[11];
            *score = (rxBuffer[12] << 8) | rxBuffer[13];
        }
        return code;
    }
    return 0xFF;
}

uint8_t deleteTemplate(uint16_t id, uint16_t count) {
    uint8_t data[4] = {(uint8_t)(id >> 8), (uint8_t)(id & 0xFF),
                       (uint8_t)(count >> 8), (uint8_t)(count & 0xFF)};
    sendCommand(CMD_DELETCHAR, data, 4);
    int16_t len = receiveResponse(rxBuffer, 2000);
    return (len > 0) ? getConfirmCode(rxBuffer, len) : 0xFF;
}

uint8_t emptyLibrary() {
    sendCommand(CMD_EMPTY, NULL, 0);
    int16_t len = receiveResponse(rxBuffer, 3000);
    return (len > 0) ? getConfirmCode(rxBuffer, len) : 0xFF;
}

int16_t findEmptySlot() {
    for (int page = 0; page < 1; page++) {
        uint8_t data[1] = {(uint8_t)page};
        sendCommand(CMD_READINDEXTABLE, data, 1);
        int16_t len = receiveResponse(rxBuffer, 1000);
        if (len > 0 && getConfirmCode(rxBuffer, len) == 0x00) {
            for (int i = 0; i < 32; i++) {
                uint8_t byte = rxBuffer[10 + i];
                for (int bit = 0; bit < 8; bit++) {
                    if (!(byte & (1 << bit))) {
                        return page * 256 + i * 8 + bit;
                    }
                }
            }
        }
    }
    return -1;
}

int16_t findSlotForFinger(int fingerId) {
    if (fingerId < 0 || fingerId > 9) return -1;
    prefs.begin("fingers", true);
    for (int slot = 0; slot < librarySize; slot++) {
        String key = "i" + String(slot);
        if (prefs.isKey(key.c_str())) {
            if (prefs.getInt(key.c_str(), -1) == fingerId) {
                prefs.end();
                return slot;
            }
        }
    }
    prefs.end();
    return -1;
}

void saveFingerName(uint16_t id, String name) {
    prefs.begin("fingers", false);
    prefs.putString(("f" + String(id)).c_str(), name);
    if (pendingFingerId >= 0 && pendingFingerId <= 9) {
        prefs.putInt(("i" + String(id)).c_str(), pendingFingerId);
    }
    prefs.end();
}

String getFingerName(uint16_t id) {
    prefs.begin("fingers", true);
    String name = prefs.getString(("f" + String(id)).c_str(), "");
    prefs.end();
    return name.length() > 0 ? name : "Finger " + String(id);
}

void deleteFingerName(uint16_t id) {
    prefs.begin("fingers", false);
    prefs.remove(("f" + String(id)).c_str());
    prefs.remove(("p" + String(id)).c_str());
    prefs.remove(("e" + String(id)).c_str());
    prefs.remove(("i" + String(id)).c_str());
    prefs.end();
}

void clearAllFingerNames() {
    prefs.begin("fingers", false);
    prefs.clear();
    prefs.end();
}

void saveFingerPassword(uint16_t id, String password) {
    prefs.begin("fingers", false);
    prefs.putString(("p" + String(id)).c_str(), password);
    prefs.end();
}

String getFingerPassword(uint16_t id) {
    prefs.begin("fingers", true);
    String pwd = prefs.getString(("p" + String(id)).c_str(), "");
    prefs.end();
    return pwd;
}

void saveFingerPressEnter(uint16_t id, bool pressEnter) {
    prefs.begin("fingers", false);
    prefs.putBool(("e" + String(id)).c_str(), pressEnter);
    prefs.end();
}

bool getFingerPressEnter(uint16_t id) {
    prefs.begin("fingers", true);
    bool pe = prefs.getBool(("e" + String(id)).c_str(), false);
    prefs.end();
    return pe;
}

int getFingerIdForSlot(uint16_t slot) {
    prefs.begin("fingers", true);
    int fingerId = prefs.getInt(("i" + String(slot)).c_str(), -1);
    prefs.end();
    return fingerId;
}

void processFingerDetection() {
    if (enrollState != ENROLL_IDLE) return;

    static unsigned long lastAttempt = 0;
    if (millis() - lastAttempt < 500) return;
    lastAttempt = millis();

    uint8_t result = captureImage();
    if (result != 0x00) return;

    result = generateChar(1);
    if (result != 0x00) {
        lastDetectResult = result;
        newDetectionAvailable = true;
        lastStatus = "Unknown finger";
        setLED(LED_ON, 0, LED_RED, 0);
        delay(2000);
        setLED(LED_OFF, 0, LED_RED, 0);
        while (captureImage() == 0x00) delay(200);
        return;
    }

    uint16_t matchId = 0, score = 0;
    result = searchFingerprint(1, 0, librarySize, &matchId, &score);

    if (result == 0x00) {
        lastDetectedFinger = getFingerName(matchId);
        lastDetectedId = matchId;
        lastDetectedScore = score;
        lastDetectResult = 0x00;
        newDetectionAvailable = true;
        lastStatus = lastDetectedFinger + " detected";
        setLED(LED_ON, 0, LED_GREEN, 0);

        typePassword(matchId);

        delay(1000);
        setLED(LED_OFF, 0, LED_GREEN, 0);
        while (captureImage() == 0x00) delay(200);

    } else {
        lastDetectedFinger = "";
        lastDetectedId = -1;
        lastDetectedScore = 0;
        lastDetectResult = result;
        newDetectionAvailable = true;
        lastStatus = "Unknown finger";
        setLED(LED_ON, 0, LED_RED, 0);
        delay(2000);
        setLED(LED_OFF, 0, LED_RED, 0);
        while (captureImage() == 0x00) delay(200);
    }
}

bool enrollCaptureToBuffer(uint8_t bufferNum) {
    uint8_t result = captureImage();
    if (result != 0x00) return false;

    result = generateChar(bufferNum);
    if (result != 0x00) {
        enrollError = "Feature extraction failed";
        enrollState = ENROLL_DONE;
        enrollSuccess = false;
        setLED(LED_ON, 0, LED_RED, 0);
        return false;
    }
    return true;
}

bool isFingerLifted() {
    return captureImage() == 0x02;
}

void processEnrollment() {
    if (enrollState == ENROLL_IDLE) return;

    if (millis() > enrollTimeout) {
        enrollState = ENROLL_DONE;
        enrollSuccess = false;
        enrollError = "Timeout";
        setLED(LED_ON, 0, LED_RED, 0);
        return;
    }

    uint8_t result;

    switch (enrollState) {
        case ENROLL_CAPTURE_1:
            if (enrollCaptureToBuffer(1)) {
                enrollState = ENROLL_LIFT_1;
                setLED(LED_FLASHING, 100, LED_GREEN, 2);
            }
            break;

        case ENROLL_LIFT_1:
            if (isFingerLifted()) {
                enrollState = ENROLL_CAPTURE_2;
                setLED(LED_OFF, 0, LED_GREEN, 0);
            }
            break;

        case ENROLL_CAPTURE_2:
            if (enrollCaptureToBuffer(2)) {
                enrollState = ENROLL_LIFT_2;
                setLED(LED_FLASHING, 100, LED_GREEN, 2);
            }
            break;

        case ENROLL_LIFT_2:
            if (isFingerLifted()) {
                enrollState = ENROLL_CAPTURE_3;
                setLED(LED_OFF, 0, LED_GREEN, 0);
            }
            break;

        case ENROLL_CAPTURE_3:
            if (enrollCaptureToBuffer(3)) {
                enrollState = ENROLL_LIFT_3;
                setLED(LED_FLASHING, 100, LED_GREEN, 2);
            }
            break;

        case ENROLL_LIFT_3:
            if (isFingerLifted()) {
                enrollState = ENROLL_CAPTURE_4;
                setLED(LED_OFF, 0, LED_GREEN, 0);
            }
            break;

        case ENROLL_CAPTURE_4:
            if (enrollCaptureToBuffer(4)) {
                enrollState = ENROLL_LIFT_4;
                setLED(LED_FLASHING, 100, LED_GREEN, 2);
            }
            break;

        case ENROLL_LIFT_4:
            if (isFingerLifted()) {
                enrollState = ENROLL_CAPTURE_5;
                setLED(LED_OFF, 0, LED_GREEN, 0);
            }
            break;

        case ENROLL_CAPTURE_5:
            if (enrollCaptureToBuffer(5)) {
                enrollState = ENROLL_LIFT_5;
                setLED(LED_FLASHING, 100, LED_GREEN, 2);
            }
            break;

        case ENROLL_LIFT_5:
            if (isFingerLifted()) {
                enrollState = ENROLL_CAPTURE_6;
                setLED(LED_OFF, 0, LED_GREEN, 0);
            }
            break;

        case ENROLL_CAPTURE_6:
            if (enrollCaptureToBuffer(6)) {
                enrollState = ENROLL_MERGING;
                setLED(LED_OFF, 0, LED_GREEN, 0);
            }
            break;

        case ENROLL_MERGING:
            result = createTemplate();
            if (result != 0x00) {
                enrollError = "Template merge failed";
                enrollState = ENROLL_DONE;
                enrollSuccess = false;
                setLED(LED_ON, 0, LED_RED, 0);
                return;
            }

            result = storeTemplate(1, pendingSlot);
            if (result != 0x00) {
                enrollError = "Store failed";
                enrollState = ENROLL_DONE;
                enrollSuccess = false;
                setLED(LED_ON, 0, LED_RED, 0);
                return;
            }

            saveFingerName(pendingSlot, pendingFingerName);
            if (pendingFingerPassword.length() > 0) {
                saveFingerPassword(pendingSlot, pendingFingerPassword);
                saveFingerPressEnter(pendingSlot, pendingPressEnter);
            }
            getTemplateCount();
            enrollState = ENROLL_DONE;
            enrollSuccess = true;
            delay(50);
            setLED(LED_ON, 0, LED_GREEN, 0);
            delay(500);
            setLED(LED_OFF, 0, LED_GREEN, 0);
            lastStatus = pendingFingerName + " enrolled";
            pendingFingerPassword = "";
            break;

        default:
            break;
    }
}

// ===== Serial Command Handler Functions =====

String getStatusJson() {
    getTemplateCount();
    String json = "{\"sensor\":" + String(sensorOk ? "true" : "false") +
                  ",\"count\":" + String(templateCount) +
                  ",\"capacity\":" + String(librarySize) +
                  ",\"last\":\"" + lastStatus + "\"}";
    return json;
}

String getDetectJson() {
    String json = "{\"detected\":" + String(newDetectionAvailable ? "true" : "false") +
                  ",\"finger\":\"" + lastDetectedFinger + "\"" +
                  ",\"id\":" + String(lastDetectedId) +
                  ",\"score\":" + String(lastDetectedScore) +
                  ",\"matched\":" + String(lastDetectedId >= 0 ? "true" : "false") +
                  ",\"lastResult\":\"0x" + String(lastDetectResult, HEX) + "\"}";
    if (newDetectionAvailable) newDetectionAvailable = false;
    return json;
}

String getFingersJson() {
    String json = "{\"fingers\":[";
    bool first = true;

    for (int page = 0; page < 1; page++) {
        uint8_t data[1] = {(uint8_t)page};
        sendCommand(CMD_READINDEXTABLE, data, 1);
        int16_t len = receiveResponse(rxBuffer, 1000);
        if (len > 0 && getConfirmCode(rxBuffer, len) == 0x00) {
            for (int i = 0; i < 32; i++) {
                uint8_t byte = rxBuffer[10 + i];
                for (int bit = 0; bit < 8; bit++) {
                    if (byte & (1 << bit)) {
                        int id = page * 256 + i * 8 + bit;
                        if (id < librarySize) {
                            if (!first) json += ",";
                            first = false;
                            json += "{\"id\":" + String(id) + ",\"name\":\"" + getFingerName(id) + "\",\"fingerId\":" + String(getFingerIdForSlot(id)) + "}";
                        }
                    }
                }
            }
        }
    }

    json += "]}";
    return json;
}

String enrollStartJson(JsonObject params) {
    if (!params.containsKey("name")) {
        return "{\"ok\":false,\"status\":\"Missing name\"}";
    }

    pendingFingerName = params["name"].as<String>();
    pendingFingerPassword = params.containsKey("password") ? params["password"].as<String>() : "";
    pendingPressEnter = params.containsKey("pressEnter") && params["pressEnter"].as<bool>();
    pendingFingerId = params.containsKey("finger") ? params["finger"].as<int>() : -1;

    int16_t existingSlot = findSlotForFinger(pendingFingerId);
    if (existingSlot >= 0) {
        deleteTemplate(existingSlot, 1);
        deleteFingerName(existingSlot);
    }

    pendingSlot = findEmptySlot();

    if (pendingSlot < 0 || pendingSlot >= librarySize) {
        return "{\"ok\":false,\"status\":\"Library full\"}";
    }

    enrollState = ENROLL_CAPTURE_1;
    enrollSuccess = false;
    enrollError = "";
    enrollTimeout = millis() + 60000;
    lastStatus = "Enrolling " + pendingFingerName;

    return "{\"ok\":true,\"status\":\"Place finger on sensor\"}";
}
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
void loop() {
    cmdHandler.loop();
    processEnrollment();
    processFingerDetection();
}

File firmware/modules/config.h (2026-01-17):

// TouchPass Configuration
// Pin definitions and constants

#ifndef TOUCHPASS_CONFIG_H
#define TOUCHPASS_CONFIG_H

#include "sdkconfig.h"

// ===== Pin Configuration =====
#if CONFIG_IDF_TARGET_ESP32S3
  // ESP32-S3: D4=GPIO5, D5=GPIO6 (Seeed XIAO silkscreen labels)
  #define FP_TX_PIN 5   // D4 - Sensor TX
  #define FP_RX_PIN 6   // D5 - Sensor RX
  // USB Serial uses UART0 (GPIO43/44) automatically
#else
  // ESP32-C6: Standard pinout
  #define FP_TX_PIN 16  // D6
  #define FP_RX_PIN 17  // D7
#endif

// ===== Fingerprint Sensor Protocol =====
#define FP_HEADER 0xEF01
#define FP_DEFAULT_ADDR 0xFFFFFFFF
#define FP_CMD_PACKET 0x01
#define FP_BAUD_RATE 57600

// Sensor Commands
#define CMD_GENIMG 0x01
#define CMD_IMG2TZ 0x02
#define CMD_SEARCH 0x04
#define CMD_REGMODEL 0x05
#define CMD_STORE 0x06
#define CMD_DELETCHAR 0x0C
#define CMD_EMPTY 0x0D
#define CMD_READSYSPARA 0x0F
#define CMD_TEMPLATENUM 0x1D
#define CMD_READINDEXTABLE 0x1F
#define CMD_AURALEDCONFIG 0x35
#define CMD_CHECKSENSOR 0x36
#define CMD_HANDSHAKE 0x40

// LED Control
#define LED_RED 0x01
#define LED_BLUE 0x02
#define LED_GREEN 0x04
#define LED_CYAN 0x06
#define LED_BREATHING 0x01
#define LED_FLASHING 0x02
#define LED_ON 0x03
#define LED_OFF 0x04

// ===== WiFi Configuration =====
#define AP_SSID "TouchPass"
#define AP_PASSWORD "touchpass"

// ===== Timing Constants =====
#define LONG_TOUCH_MS 5000
#define SENSOR_TIMEOUT_MS 3000
#define ENROLL_TIMEOUT_MS 60000

// ===== Serial Configuration =====
#define CONFIG_BAUD_RATE 115200
#define USB_WAIT_TIME_MS 3000

#endif // TOUCHPASS_CONFIG_H

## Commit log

2025-12-30 feat: initial TouchPass release
    A hardware password manager that types your passwords when you touch it with an enrolled finger.
2025-12-30 chore: restructure as open source hardware project
    - Move source code to firmware/
    - Add hardware/ with wiring documentation
    - Add enclosure/ placeholder for 3D case designs
    - Add docs/ with assembly guide
    - Add LICENSE (MIT) and CONTRIBUTING.md
    - Update README with project structure and badges
2025-12-30 fix: rename ino file to match folder name
    [firmware.ino]
2026-01-14 feat: replace WiFi AP config with USB serial Web Serial API
    BREAKING CHANGE: WiFi AP configuration mode has been completely removed
    - Replace WiFi AP mode with USB serial-based configuration
    - Add SerialCommandHandler.h for JSON serial protocol (115200 baud)
    - Create config.html single-file Web Serial configurator
    - Add KeyboardInterface.h abstraction layer for BLE/USB keyboards
    - Refactor firmware.ino to remove WiFi/WebServer dependencies
    - Map all 15 HTTP endpoints to serial commands
    - Update README with Chrome/Edge browser requirements
    - Add CHANGELOG documenting v2.0.0 breaking changes
    - Remove webpage.h (replaced by config.html)
    - Update sketch.json for ESP32-S3 target
    - Memory savings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
    [firmware.ino]
2026-01-17 feat: add ESP32-S3 support with USB HID and WiFi AP config
    - Add ESP32-S3 support with native USB HID keyboard
    - Replace Web Serial config with WiFi AP configuration (192.168.4.1)
    - Add embedded web UI with hand diagram for finger enrollment
    - Support both USB and BLE keyboard modes (switchable via web UI)
    - Add WiFi toggle via long touch (5 seconds)
    - Update documentation for dual-chip support and wiring
    [firmware.ino]
2026-01-17 fix: correct USB mode for Web Serial API compatibility
    CRITICAL FIX: Switch from Hardware CDC (hwcdc) to USB-OTG TinyUSB mode
    for proper Web Serial API bidirectional communication.
    The ESP32-S3 has two USB peripherals:
    1. USB Serial/JTAG Controller (hwcdc) - hardware-based, has issues with
    bidirectional communication in Web Serial API
    2. USB-OTG CDC (TinyUSB) - software-based, full Web Serial API support
    Changes:
    - Set USBMode=default (TinyUSB) instead of USBMode=hwcdc
    - Set CDCOnBoot=default (Enabled) to keep USB port after boot
    - Add extensive debug logging throughout serial communication
    - Update firmware.ino header with correct upload flags
    - Create comprehensive programming-guide.m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
    [config.h, fingerprint.cpp]
2026-01-17 refactor: remove all debug logging and simplify code
    Remove extensive debug logging added during troubleshooting:
    - config.html: Remove verbose console.log statements
    - firmware.ino: Remove debug prints from setup() and loop()
    - SerialCommandHandler.h: Remove debug output from loop() and sendResponse()
    Code is now clean and production-ready while maintaining full functionality.
2026-01-21 chore: finalize project structure and add visual documentation
    - Move firmware modules from modules_wip to modules
    - Add project images to docs/images (demo GIF, hardware photos, UI screenshots)
    - Update README with embedded images and visual guides
    - Remove outdated documentation and backup files
    - Add 3D printable enclosure STL file
    - Clean up project structure for release
    [case touchPass.stl]
